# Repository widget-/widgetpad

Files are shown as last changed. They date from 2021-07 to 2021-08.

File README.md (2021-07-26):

# Widgetpad v0

Hi, I'm Widget, and these are the files for my ITG dance/travel pad.

This is the "v0" version, currently in prototype status. I don't plan
on deviating too far from these plans, but there are more adjustments
I still want to make to make the pad easier to manufacture, easier to
fork the source code for, and have it perform more consistently.

You can find me on the Stamina Nation discord causing problems in #pads.

If you live in Chicago and can pass stamina 16's or higher, I would be
interested in having you try out the prototype in person for feedback.
Let me know on Discord.

## Motivation

Current pads either suck or are >$1000. LTEKs are acceptable but need
significant modding using custom microcontrollers and the fragile "penny
mod", so why not just make a new pad?

Currently it's mainly competing with Bandit's
[Build This Travel Pad](https://www.youtube.com/watch?v=y6wGYLE0YI4)
and [Bandit's Terrific Travel Pad](https://github.com/BanditsTerrificTravelPad/bttp)
budget designs.

## Specs

* Aluminum extrusion frame (2020 profile)
* 1/2" acrylic panels
* Arduino Pro Micro microcontroller (but with plans to switch to Teensy
  4.0)
* Force-sensitive resistors for configurable sensitivity
  * Allows for rather extreme sensitivity if made with good tolerances
* Optional LED grid PCBs (WS2812C LEDs)

## License

GNU GPL v2. See LICENSE for full text.

## Demo

YouTube demo video (https://www.youtube.com/watch?v=cCqrD7NEzos)

## Requirements

### Materials

* Arduino Pro Micro or Teensy 2.0 or higher
* 4x 220 ohm resistors
* Some wire to extend FSR connections
* Panels, cut or precut:
  * Either
    * 4x 12mm thickness 280mm x 280mm acrylic panels (1/2" thickness
      11"x11") or larger
  * Or
    * 1x 280mm x 280mm precut acrylic center panel
    * 4x 280mm x 125mm precut acrylic side panels
    * 4x 125mm x 125mm precut acrylic corner panels (optional)
  * Optionally, acetal (a.k.a. POM, Delrin) as a slipperier center panel
    instead of acrylic
* Aluminum extrusion (2020 profile)
  * All taps should be M6 taps with 10mm depth
    * Extra depth is acceptable but may require longer M6 threaded rods
  * 2x 544mm extrusions
    * Drill 6mm at holes at 10mm, 129.5mm, 414.5mm, and 534mm
    * Countersink these holes for your 6mm bolts as well
  * 4x 504mm extrusions, both ends tapped
    * Drill 6mm holes at 109.5mm and 394.5mm
    * For 2 extrusions, countersink these holes for your 6mm bolts as
      well
    * For the other 2 extrusions, extra holes for wiring recommended
  * 2x 265mm extrusions, both ends tapped
    * Extra holes through the center for wiring recommended
  * 4x 99.5mm extrusions, both ends tapped
    * Extra holes through the center for wiring recommended
* Force sensitive resistors (4x 200mm [Interlink 408](https://buyinterlinkelectronics.com/collections/new-standard-force-sensors/products/fsr-model-408-200mm-length) or 8x
  [Interlink 400](https://buyinterlinkelectronics.com/collections/new-standard-force-sensors/products/fsr-model-400))
* 12x countersunk M6x30mm bolts
* 12x hex-head M6x30mm bolts
* 4x M6x40mm threaded rods
* 16x M6 threaded inserts for plastic
* 40x M5x10 bolts
* 40x M5 hammer nuts for 2020 aluminum extrusion
* An "engineering" filament for 3D printed parts, such as PETG, nylon,
  or polycarbonate
* Optional: cross brackets and angle brackets for stability
* Optional: rubber bumpers for floor safety and/or better pad sensitivity
* Optional: 128 [WS2812C-5050](https://lcsc.com/product-detail/Light-Emitting-Diodes-LED_5050-RGBIntegrated-Light-4Pin_C114587.html) LEDs for PCBs
* Optional: 8x 1x2 2.54mm-pitch right-angle male PCB headers for PCBs
* Optional: 4x [5.04mm-pitch 1x2 screw terminals](https://lcsc.com/product-detail/Screw-terminal_Ningbo-Kangnex-Elec-WJ500V-5-08-2P_C8465.html) for PCBs
* Optional: 8x [5.04mm-pitch 1x3 screw terminals](https://lcsc.com/product-detail/Screw-terminal_Ningbo-Kangnex-Elec-WJ500V-5-08-3P_C72334.html) for PCBs

### Equipment

* Table saw if acrylic cutting needed
* Drill press with 6mm (1/4") drill bit and 45° countersink bit
* Table router and roundover bit or lots of sandpaper for smooth edges
* 3mm and 4mm allen keys
* 3D printer for panel mounts
* A heated tool of some sort, such as a soldering iron or a lighter and
  a rod of some type, for inserting the threaded inserts
* Soldering iron is required if assembling PCBs
* DuPont wire crimpers may be useful for making "extension cords" for
  the FSR connectors

### 3D printed parts

3D printed parts can be found in the `3d/` folder.

Parts are designed using [OpenSCAD](https://openscad.org/) with the
[BOSL2](https://github.com/revarbat/BOSL2) library. OpenSCAD nightlies
and BOSL2 master branch are recommended.

Corner bracket mounts will need to be 3D printed to connect the panels
to the aluminum frame.

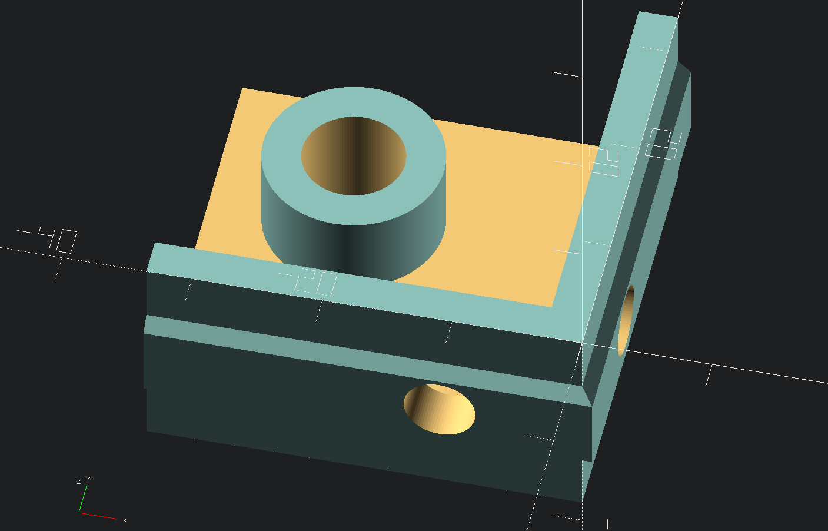
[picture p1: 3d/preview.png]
3D printed corner bracket


Strong filaments, at a minimum PETG but preferably
nylon or polycarbonate will be required. Brittle filaments like PLA,
ABS, HIPS, and ASA may crack. High-rigidity TPU filaments (Shore
hardness 98A or higher) may work, but soft filaments may cause the
panels to slide during play.

A soldering iron or other heating tool will be needed to melt the
threaded inserts into the 3D printed part for the panels to connect to.

PCB mounts may also be 3D printed.

A housing will eventually be designed for the microcontroller but not
as part of v0.

### PCBs

#### Microcontroller breakout

The microcontroller breakout is for a Teensy 4.0 or Teensy 4.1.

The Teensy 4.0 will allow control of up to 10 FSRs, which can map to
up to 10 panels, or 2 FSRs on up to 5 panels.

The Teensy 4.1 will allow control of up to 18 FSRs, which allows an
amount of flexibility with regards to a high-end setup:

* 4 FSRs on each of 4 panels (dance)
* 2 FSRs on each of 8 or 9 panels (techno)
* 2 or 3 FSRs on 4 panels and 4 on a center panel (pump)
* 4 FSRs on 4 panels, and 2 on a center panel (pump)

The breakout also has:

* A 3-pin JST-HX connection for panel LEDs
* 9 LEDs for checking FSR pressed status
* 4 external buttons, for an external arcade button assembly
* 3 internal buttons for controlling LED brightness, and triggering
  an as-yet-unwritten pad calibration
* A buzzer or speaker, to add audio "tactility" to pressing the panels
* A jumper to bridge USB power with the external power input for LEDs

The breakout is designed using KiCAD and uses
[teensy_library](https://github.com/XenGi/teensy_library) and
[teensy.pretty](https://github.com/XenGi/teensy.pretty) by
[XenGi](https://github.com/XenGi), released under the BSD license.

#### Panels

The PCBs are designed using [KiCAD](https://www.kicad.org/).

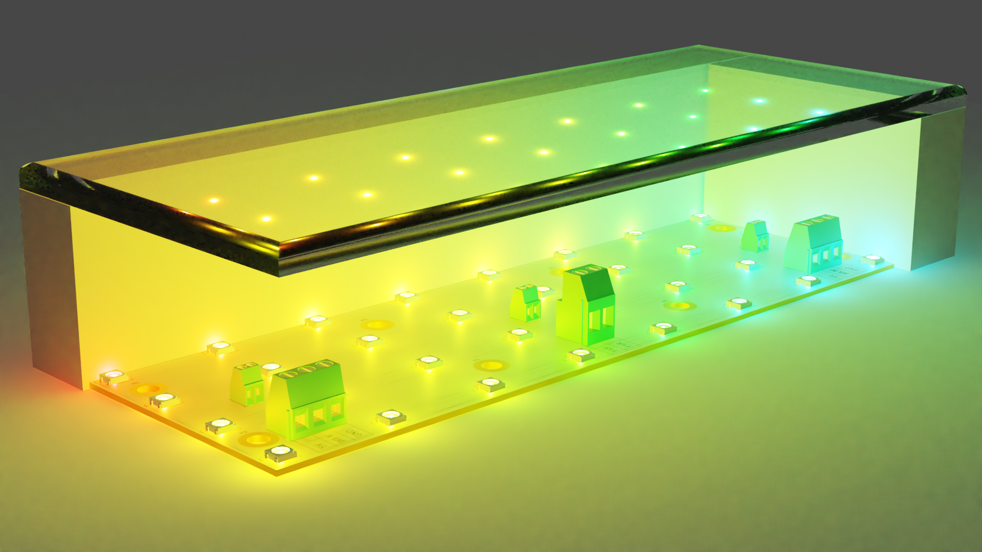
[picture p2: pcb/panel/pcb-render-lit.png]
PCB Render


The PCBs each hold an 8x4 grid of WS2812C LEDs. An external 5V power
source is recommended if using LEDs.

Each PCB has screw terminals for connecting the WS2812C inputs and
outputs. In addition, there are 3 positions of screw terminals and
headers for connecting one or more FSRs. Multiple FSRs would be wired
in parallel.

## Construction

### Frame

1) Cut all aluminum extrusion pieces to length, if not precut
2) Cut drills and countersinks in extrusion
3) Tap all extrusion pieces 10mm deep except the two longest ones, if
   not pretapped
4) Use threaded rods to attach small extrusions "through" the two longer
   center ones
5) Bolt the four second-longest extrusions to the longest two extrusions
6) Insert threaded inserts (using heat) into 3D printed panel mounts
7) Attach 3D printed panel mounts to corners of frame using M5 hammer
   nuts
8) Optionally add cross braces and corner brackets, and add rubber feet
   to the bottom of the frame

### Panels

1) Cut all panels to correct size
2) Preferably using a drill press, cut holes 30mm inset from each corner
   * Four holes on the center panel
   * Two adjacent holes on the edge panels
   * Two opposing holes on the corner panels
3) Use a countersink bit to countersink the holes
4) Using a table router with a roundover bit or lots of sandpaper,
   smooth the edges so that your socks don't get torn up

### Wiring

This pad uses typical wiring for FSR-based pads. Each FSR should connect
to an analog pin an the microcontroller with a 220 ohm pulldown resistor
with the other side connected to VCC.

LED boards will need a connection to VCC, GND, and a data pin, typically
D10 on the Arduino Pro Micro.

An external 5V power source is recommended if using LEDs.

One or more large capacitors (47μF or larger) across +5V and GND may
help with signal stability if the LEDs are causing noise in the FSR
signals.

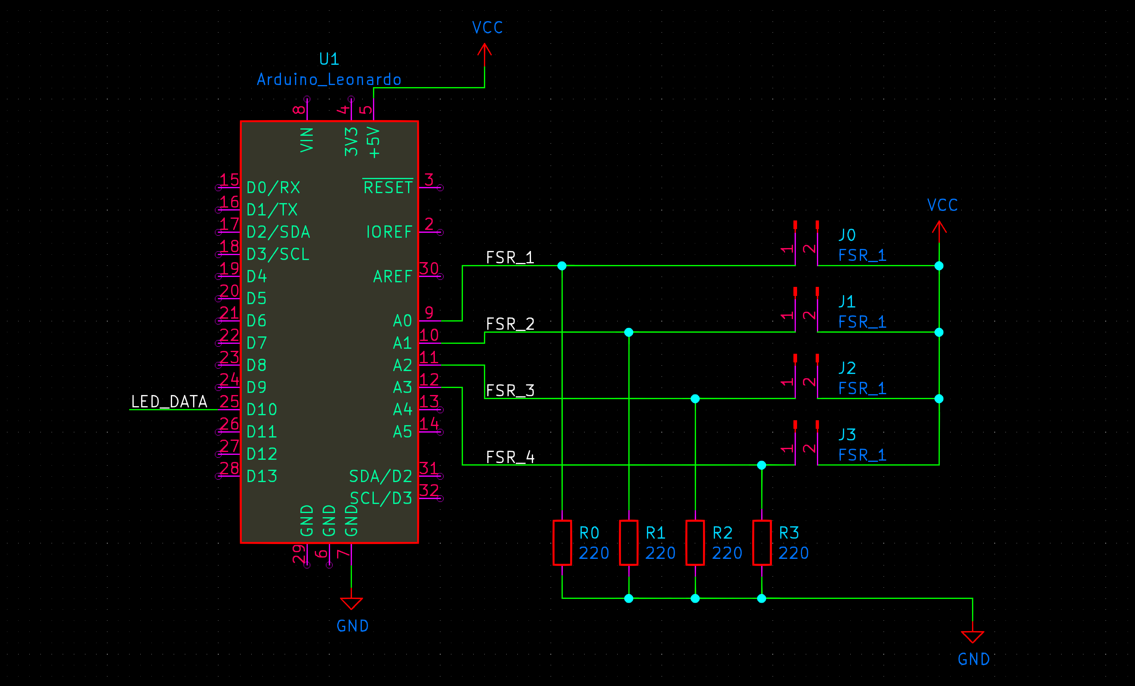
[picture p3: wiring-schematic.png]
Wiring diagram


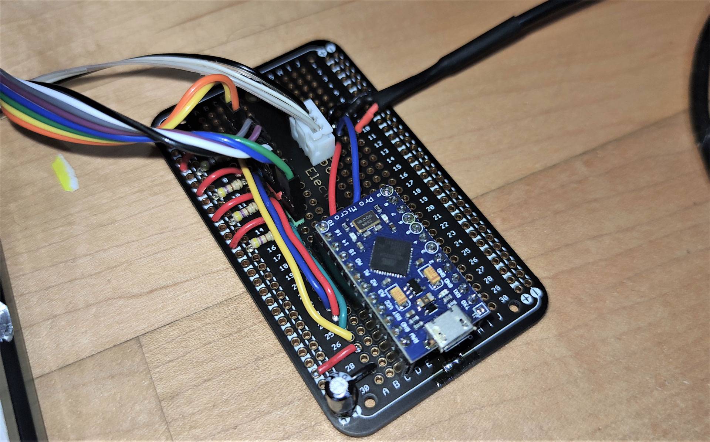
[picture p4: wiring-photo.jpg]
Wiring photo


See also [this diagram](https://cdn.discordapp.com/attachments/591851159795400734/841802090543054849/Untitled-1.png) by Bandit.

## Dimensions

The dimensions are currently calculated using Fusion 360, but I hate
Fusion 360 so eventually I'll change it over to OpenSCAD as well.

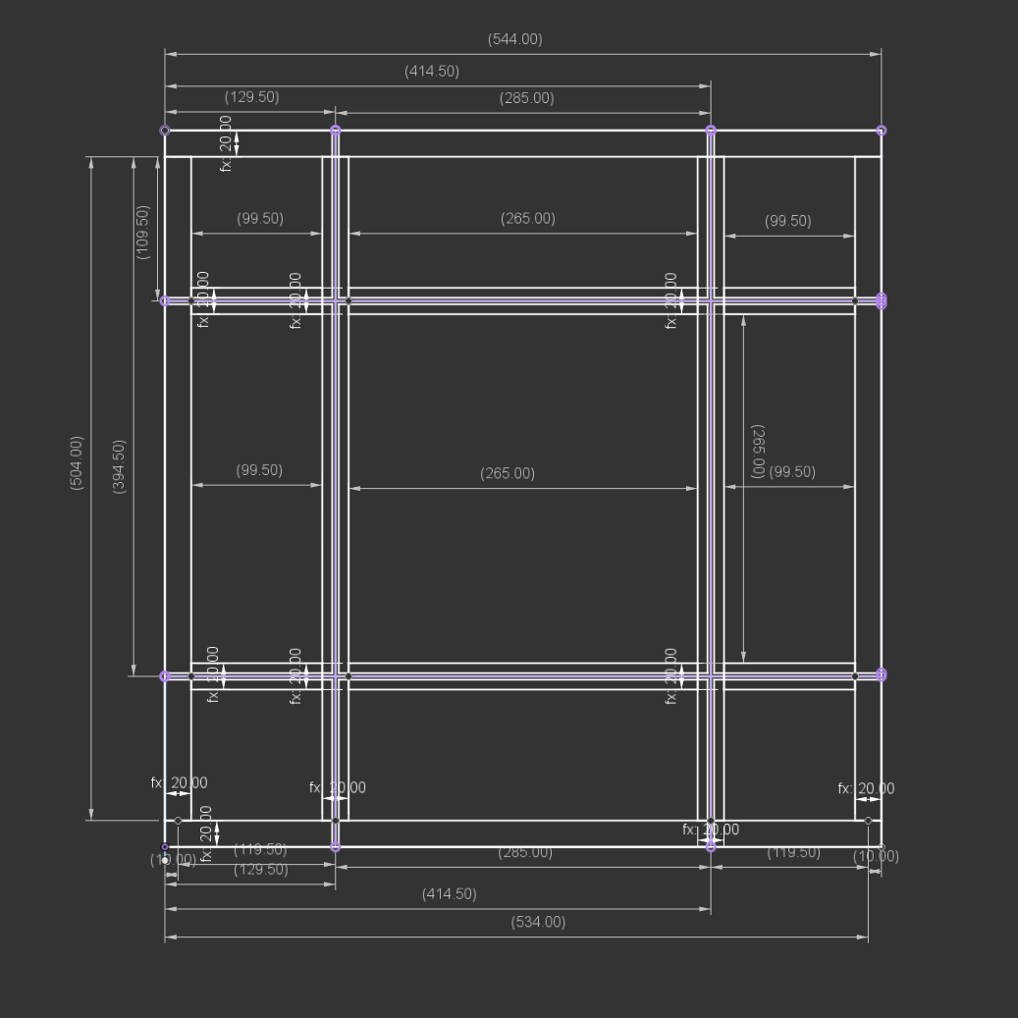
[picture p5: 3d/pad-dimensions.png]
Pad dimensions


## Firmware

The firmware is still a work in progress and can be found at
[widget-/bttp-firmware](https://github.com/widget-/bttp-firmware). It is
a fork of Bandit's [BTTP](https://github.com/BanditsTerrificTravelPad/bttp)
pad's firmware.

Currently it supports joystick or keyboard input, and allows an arbitrary
amount of buttons with corresponding optional LED strips. Sensitivity
can be adjusted either in the firmware or with a tool such as the
[bttp-config-tool](https://github.com/BanditsTerrificTravelPad/bttp-config-tool).

## Special thanks

* Bandit, for motivating me to make this pad, as well as giving me one
  of his prototype pads to play on.
* [dominick](https://www.youtube.com/channel/UCpeNRVOVrqx_lras7hbOOrQ)
  and [teejusb](https://github.com/teejusb) for their help and experience
* The rest of #pads for keeping me motivated
* [South Side Hackerspace](https://sshchicago.org/), for having all the equipment used to create
  the prototype

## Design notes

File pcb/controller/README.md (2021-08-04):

# Teensy 4.0/4.1 Breakout PCB

This is a breakout board for the Teensy 4.0 or Teensy 4.1
microcontroller, intended for use with custom dance pads for games like
ITG and Pump It Up.

This PCB is designed in KiCAD. If the dependencies for the board are not
detected automatically, add the common_lib folder next to this folder
to your KiCAD's search paths for both libraries and footprints.

## Features

* Many FSR outputs with 10kΩ resistors
  * 18 outputs with Teensy 4.1
  * 10 outputs with Teensy 4.0
* Status LEDs for FSR activation status
* 3-pin JST-XH connector for WS2811/WS2812 panel LED boards or strips
* Internal buttons for controlling LED brightness and activating pad
  automatic calibration
* Connection points for external navigation buttons
* Buzzer for audio feedback
* DC barrel jack connector for external LED power
  * Jumper for using USB power to power LEDs instead
* Headers for all soldered Teensy pins, to allow for use cases beyond
  just this board

## License

GNU GPL v2. See the LICENSE file in this project's root for full text.

## Schematic

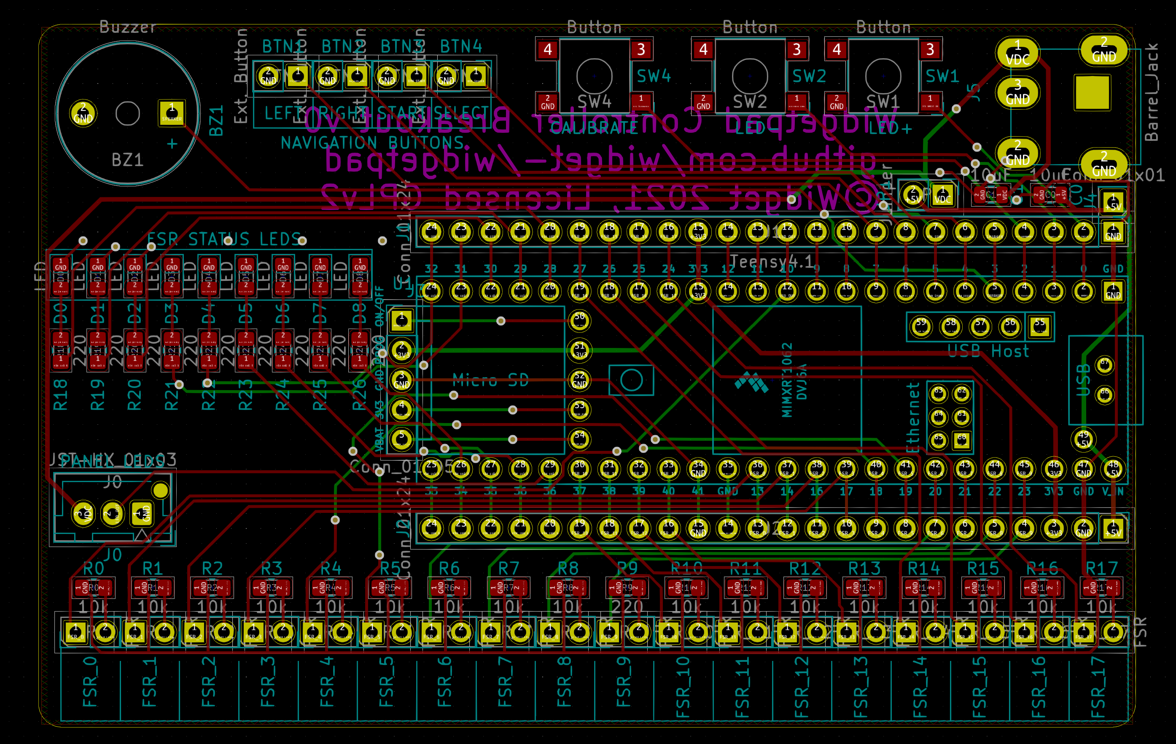
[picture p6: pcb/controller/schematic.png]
Board schematic


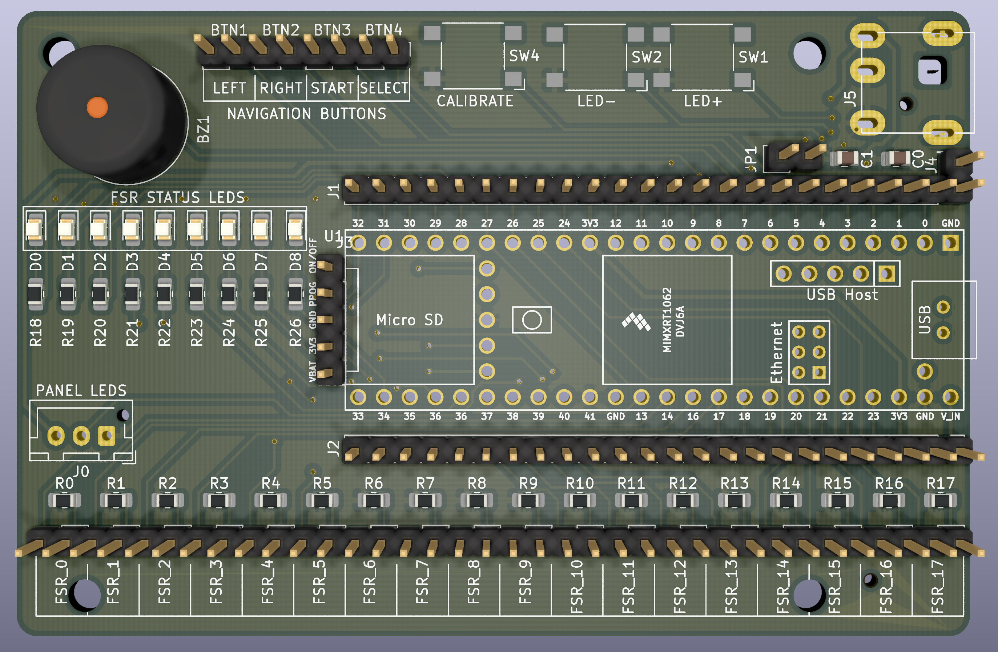
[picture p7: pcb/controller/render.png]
Board render


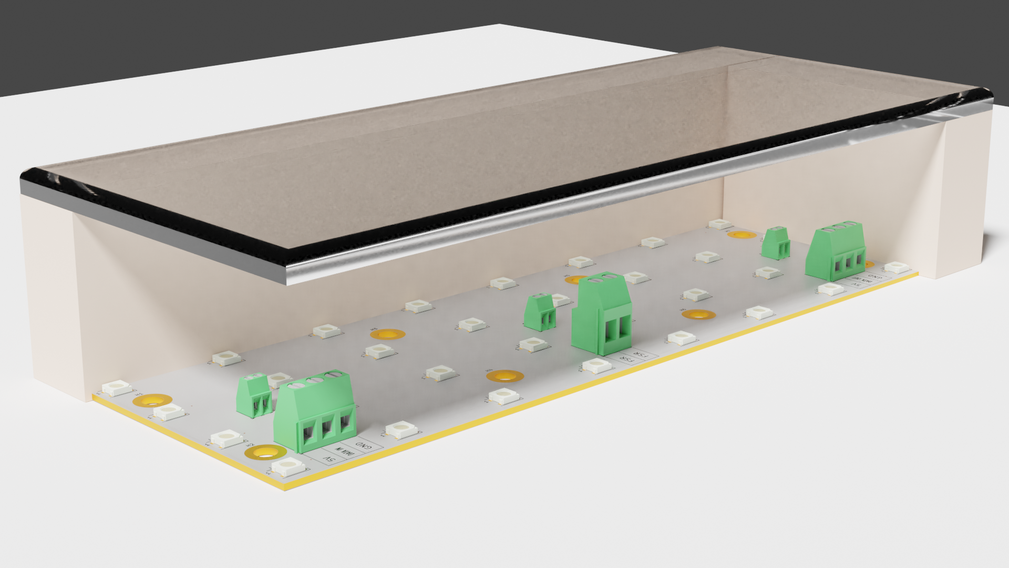
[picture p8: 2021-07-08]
pcb/panel_led/pcb-render-unlit.png

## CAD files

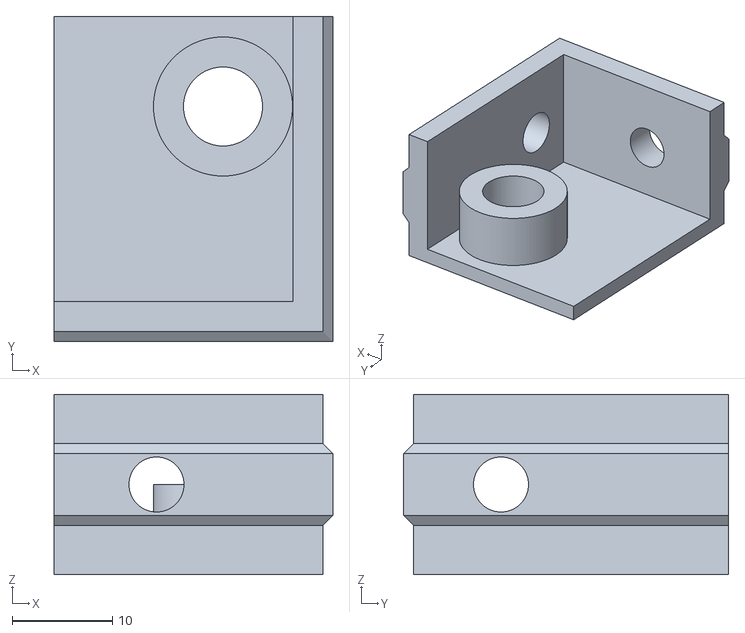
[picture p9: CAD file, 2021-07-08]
3d/dance-pad-edgeL-corner-bracket.stl
27.9 x 32.5 x 18.0

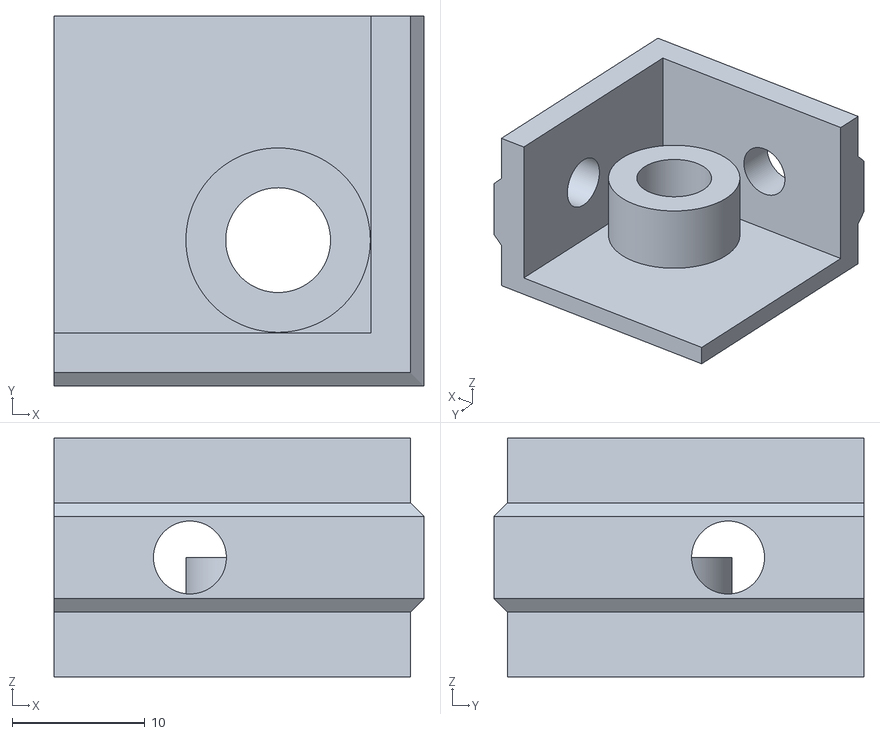
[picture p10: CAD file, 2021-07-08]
3d/dance-pad-corner-corner-bracket.stl
27.9 x 27.9 x 18.0

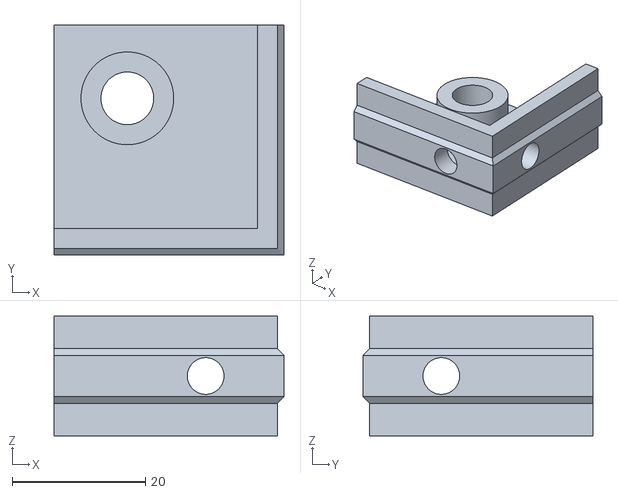
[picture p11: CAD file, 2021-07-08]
3d/dance-pad-center-corner-bracket.stl
34.5 x 34.5 x 18.0

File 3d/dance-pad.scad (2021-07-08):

// This model requires the BOSL2 library. Get it from https://github.com/revarbat/BOSL2
include <BOSL2/std.scad>

corner_inset = 29;

extrusion_width = 20;
extrusion_height = 20;
extrusion_notch = 6.2;
extrusion_protrusion = 1;

2020_bolt_diameter = 5.5;
2020_bolt_length = 14;
2020_cap_diameter = 10;
2020_cap_height = 1.5;
nut_diameter = 8;
nut_thickness = 4.6;

thickness = 3;
base_thickness = 2;
insert_thickness = 8;

panel_width = 280;
panel_thickness = 25.4/4;
panel_bolt_diameter = 6;

insert_diameter = 7.9;
insert_depth = 8;

panel_spacing = 5;

extrusion_height_tolerance = 2;

function option(index, a, b, c) =
    (index == 1) ? a :
    (index == 2) ? b :
    c;


$fa = 0.5;
$fs = 0.2;

module panel_preview() {
    // center panel
    // left(panel_width/2-extrusion_width/4-panel_spacing/2)
    left(panel_width/2-extrusion_width)
    back(panel_width/2-extrusion_width)
    difference() {
        cuboid([panel_width, panel_width, panel_thickness], rounding=panel_thickness/2, edges=TOP);

        xcopies(panel_width-corner_inset*2)
        ycopies(panel_width-corner_inset*2)
        cyl(d=panel_bolt_diameter, h=panel_thickness+1);
    }
}

module corner_bracket(inset_x, inset_y, extra_bolt_offset_x=0, extra_bolt_offset_y=0) {
    _width = inset_x + panel_bolt_diameter + thickness + extra_bolt_offset_x;
    _length = inset_y + panel_bolt_diameter + thickness + extra_bolt_offset_y;
    difference() {
        // base cube
        union() {
            cuboid([_width, _length, extrusion_height-extrusion_height_tolerance], anchor=RIGHT+FRONT+TOP);
            down((extrusion_height-extrusion_height_tolerance)/2) {
                cuboid([_width, extrusion_protrusion*2, extrusion_notch+extrusion_protrusion*2], chamfer=extrusion_protrusion, edges="X", anchor=RIGHT);
                cuboid([extrusion_protrusion*2, _length, extrusion_notch+extrusion_protrusion*2], chamfer=extrusion_protrusion, edges="Y", anchor=FRONT);
                cuboid([extrusion_protrusion*2, extrusion_protrusion*2, extrusion_notch+extrusion_protrusion*2], chamfer=extrusion_protrusion, edges=["X", "Y"]);
            }
        }

        // cut out inner section
        translate([-thickness, thickness, base_thickness])
        cuboid([_width, _length, extrusion_height-extrusion_height_tolerance], anchor=RIGHT+FRONT+TOP);

        // hole for threaded insert
        left(inset_x)
        back(inset_y)
        cyl(h=extrusion_height*2+1, d=insert_diameter);

        // 2020 mounting screws
        // translate([-(thickness+2020_cap_diameter/2+2020_cap_height/2), thickness+2020_cap_diameter/2+2020_cap_height, -(extrusion_height-extrusion_height_tolerance)/2])
        // translate([-thickness, thickness, -(extrusion_height-extrusion_height_tolerance)/2])
        down((extrusion_height-extrusion_height_tolerance)/2)
        left(thickness)
        back(thickness+2020_cap_diameter/2+2020_cap_height/2 + extra_bolt_offset_y) {
            cyl(h=max(_width, _length)*2+1, d=2020_bolt_diameter, orient=LEFT);
            cyl(h=2020_bolt_length, d=2020_cap_diameter, orient=LEFT, anchor=BOTTOM);
        }

        down((extrusion_height-extrusion_height_tolerance)/2)
        back(thickness) 
        left(thickness+2020_cap_diameter/2+2020_cap_height/2 + extra_bolt_offset_x) {
            cyl(h=max(_width, _length)*2+1, d=2020_bolt_diameter, orient=BACK);
            cyl(h=2020_bolt_length, d=2020_cap_diameter, orient=BACK, anchor=BOTTOM);
        }
    }
    
    left(inset_x)
    back(inset_y)
    down((extrusion_height-extrusion_height_tolerance)/2)
    tube(h=insert_thickness, id=insert_diameter, od=insert_diameter+thickness*2, anchor=TOP);
}

module corner_bracket_center_panel() {
    inset = corner_inset - extrusion_width/4 - panel_spacing/2;
    corner_bracket(inset, inset, 2, 2);
}

module corner_bracket_edge_panel_l() {
    inset_x = corner_inset - extrusion_width;
    inset_y = corner_inset - extrusion_width/4 - panel_spacing/2;
    corner_bracket(inset_x, inset_y, insert_diameter);
}

module corner_bracket_edge_panel_r() {
    inset_x = corner_inset - extrusion_width/4 - panel_spacing/2;
    inset_y = corner_inset - extrusion_width;
    corner_bracket(inset_x, inset_y, 0, insert_diameter);
}
module corner_bracket_corner_panel() {
    inset_x = corner_inset - extrusion_width;
    inset_y = corner_inset - extrusion_width;
    corner_bracket(inset_x, inset_y, insert_diameter, insert_diameter);
}

// corner_bracket_center_panel();

// corner_bracket_edge_panel_l();
corner_bracket_edge_panel_r();

// corner_bracket_corner_panel();

if ($preview)
color("#FFFFFF66")
up(panel_thickness/2)
panel_preview();

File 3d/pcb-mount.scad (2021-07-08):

// This model requires the BOSL2 library. Get it from https://github.com/revarbat/BOSL2
include <BOSL2/std.scad>


hole_spacing = 44;
hole_length = 35;
hole_diameter = 5.5;

extrusion_notch = 6; // 6.2 officially
extrusion_protrusion = 1; // 1mm chamfer makes 8mm beginning of opening
extrusion_height = 20;
extrusion_height_tolerance = 2;

2020_bolt_diameter = 5.5;
2020_bolt_length = 14;

thickness = 4;
base_thickness = 2;
screw_extra_spacing = 5;

_width = hole_spacing + screw_extra_spacing * 2 + hole_diameter;
_length = hole_length + screw_extra_spacing*2 + thickness;

$fa = 1;
$fs = .5;

difference() {
    union() {
        cuboid([_width, thickness, extrusion_height-extrusion_height_tolerance], anchor=FRONT+BOTTOM);
        up((extrusion_height-extrusion_height_tolerance)/2)
        cuboid([_width, extrusion_protrusion*2, extrusion_notch+extrusion_protrusion*2], chamfer=extrusion_protrusion, edges="X");
    }

    up((extrusion_height-extrusion_height_tolerance)/2)
    back(thickness)
    xcopies(l=hole_spacing)
    cyl(h=max(_width, _length)*2+1, d=2020_bolt_diameter, orient=BACK);
}

xcopies(l=hole_spacing)
difference() {
    cuboid([hole_diameter+screw_extra_spacing*2, _length, base_thickness], anchor=FRONT+BOTTOM, rounding=screw_extra_spacing, edges=[BACK+LEFT, BACK+RIGHT]);
    back(thickness+hole_length/2+screw_extra_spacing)
    cuboid([hole_diameter, hole_length, base_thickness*3], rounding=hole_diameter/2, edges="Z");
}

xflip_copy(_width/2-(hole_diameter+screw_extra_spacing*2-base_thickness)/2)
yrot(-90)
back(thickness)
zcopies(hole_diameter+screw_extra_spacing*2-base_thickness)
right_triangle([(extrusion_height-extrusion_height_tolerance)/2, (extrusion_height-extrusion_height_tolerance)/2, base_thickness]);

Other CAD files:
3d/dance-pad-edgeR-corner-bracket.stl

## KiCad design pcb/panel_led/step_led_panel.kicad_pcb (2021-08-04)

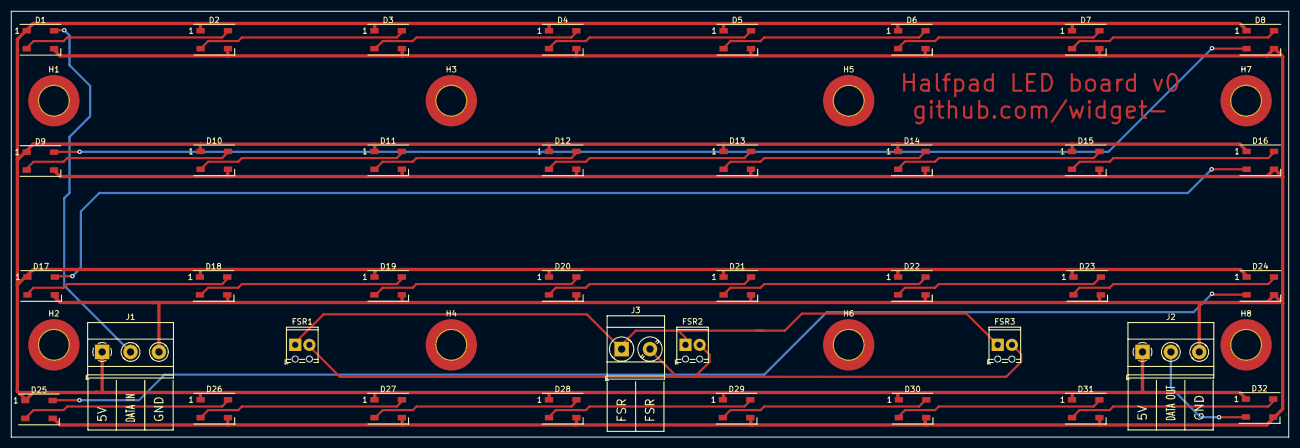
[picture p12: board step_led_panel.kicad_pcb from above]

Board: 2 copper layers, 228.6 x 76.2 mm, 46 parts (0 on the bottom side), 37 nets.

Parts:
D1, D2, D3, D4, D5, D6, D7, D8, D9, D10, D11, D12, D13, D14, D15, D16, D17, D18, D19, D20, D21, D22, D23, D24, D25, D26, D27, D28, D29, D30, D31, D32: WS2812; LED_WS2812B_PLCC4_5.0x5.0mm_P3.2mm
FSR1, FSR2, FSR3: Screw_Terminal_01x02; TerminalBlock_Phoenix_MPT-0,5-2-2.54_1x02_P2.54mm_Horizontal
H1, H2, H3, H4, H5, H6, H7, H8: MountingHole; MountingHole_5.3mm_M5_DIN965_Pad_TopOnly
J1, J2: Screw_Terminal_01x03; TerminalBlock_Phoenix_MKDS-1,5-3-5.08_1x03_P5.08mm_Horizont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
J3: Screw_Terminal_01x02; TerminalBlock_Phoenix_MKDS-3-2-5.08_1x02_P5.08mm_Horizontal

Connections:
+5V: D1.1, D2.1, D3.1, D4.1, D5.1, D6.1, D7.1, D8.1, D10.1, D11.1, D12.1, D13.1, D14.1, D15.1, D16.1, D18.1, D19.1, D20.1, D21.1, D22.1, D23.1, D24.1, D26.1, D27.1, D28.1, D29.1, D30.1, D31.1, D32.1, J1.1, J2.1
/D_IN: D1.4, J1.2
/D_OUT: D32.2, J2.2
GND: D1.3, D2.3, D3.3, D4.3, D5.3, D6.3, D7.3, D8.3, D10.3, D11.3, D12.3, D13.3, D14.3, D15.3, D16.3, D18.3, D19.3, D20.3, D21.3, D22.3, D23.3, D24.3, D26.3, D27.3, D28.3, D29.3, D30.3, D31.3, D32.3, J1.3, J2.3
unnamed: D1.2, D2.4
unnamed: D2.2, D3.4
unnamed: D3.2, D4.4
unnamed: D4.2, D5.4
unnamed: D5.2, D6.4
unnamed: D6.2, D7.4
unnamed: D7.2, D8.4
unnamed: D8.2, D9.4
unnamed: D10.2, D11.4
unnamed: D9.2, D10.4
unnamed: D11.2, D12.4
unnamed: D12.2, D13.4
unnamed: D13.2, D14.4
unnamed: D14.2, D15.4
unnamed: D15.2, D16.4
unnamed: D16.2, D17.4
unnamed: D17.2, D18.4
unnamed: D18.2, D19.4
unnamed: D19.2, D20.4
unnamed: D20.2, D21.4
unnamed: D21.2, D22.4
unnamed: D22.2, D23.4
unnamed: D23.2, D24.4
unnamed: D24.2, D25.4
unnamed: D25.2, D26.4
unnamed: D26.2, D27.4
unnamed: D27.2, D28.4
unnamed: D28.2, D29.4
unnamed: D29.2, D30.4
unnamed: D30.2, D31.4
unnamed: D31.2, D32.4
unnamed: FSR1.1, FSR2.1, FSR3.1, J3.1
unnamed: FSR1.2, FSR2.2, FSR3.2, J3.2

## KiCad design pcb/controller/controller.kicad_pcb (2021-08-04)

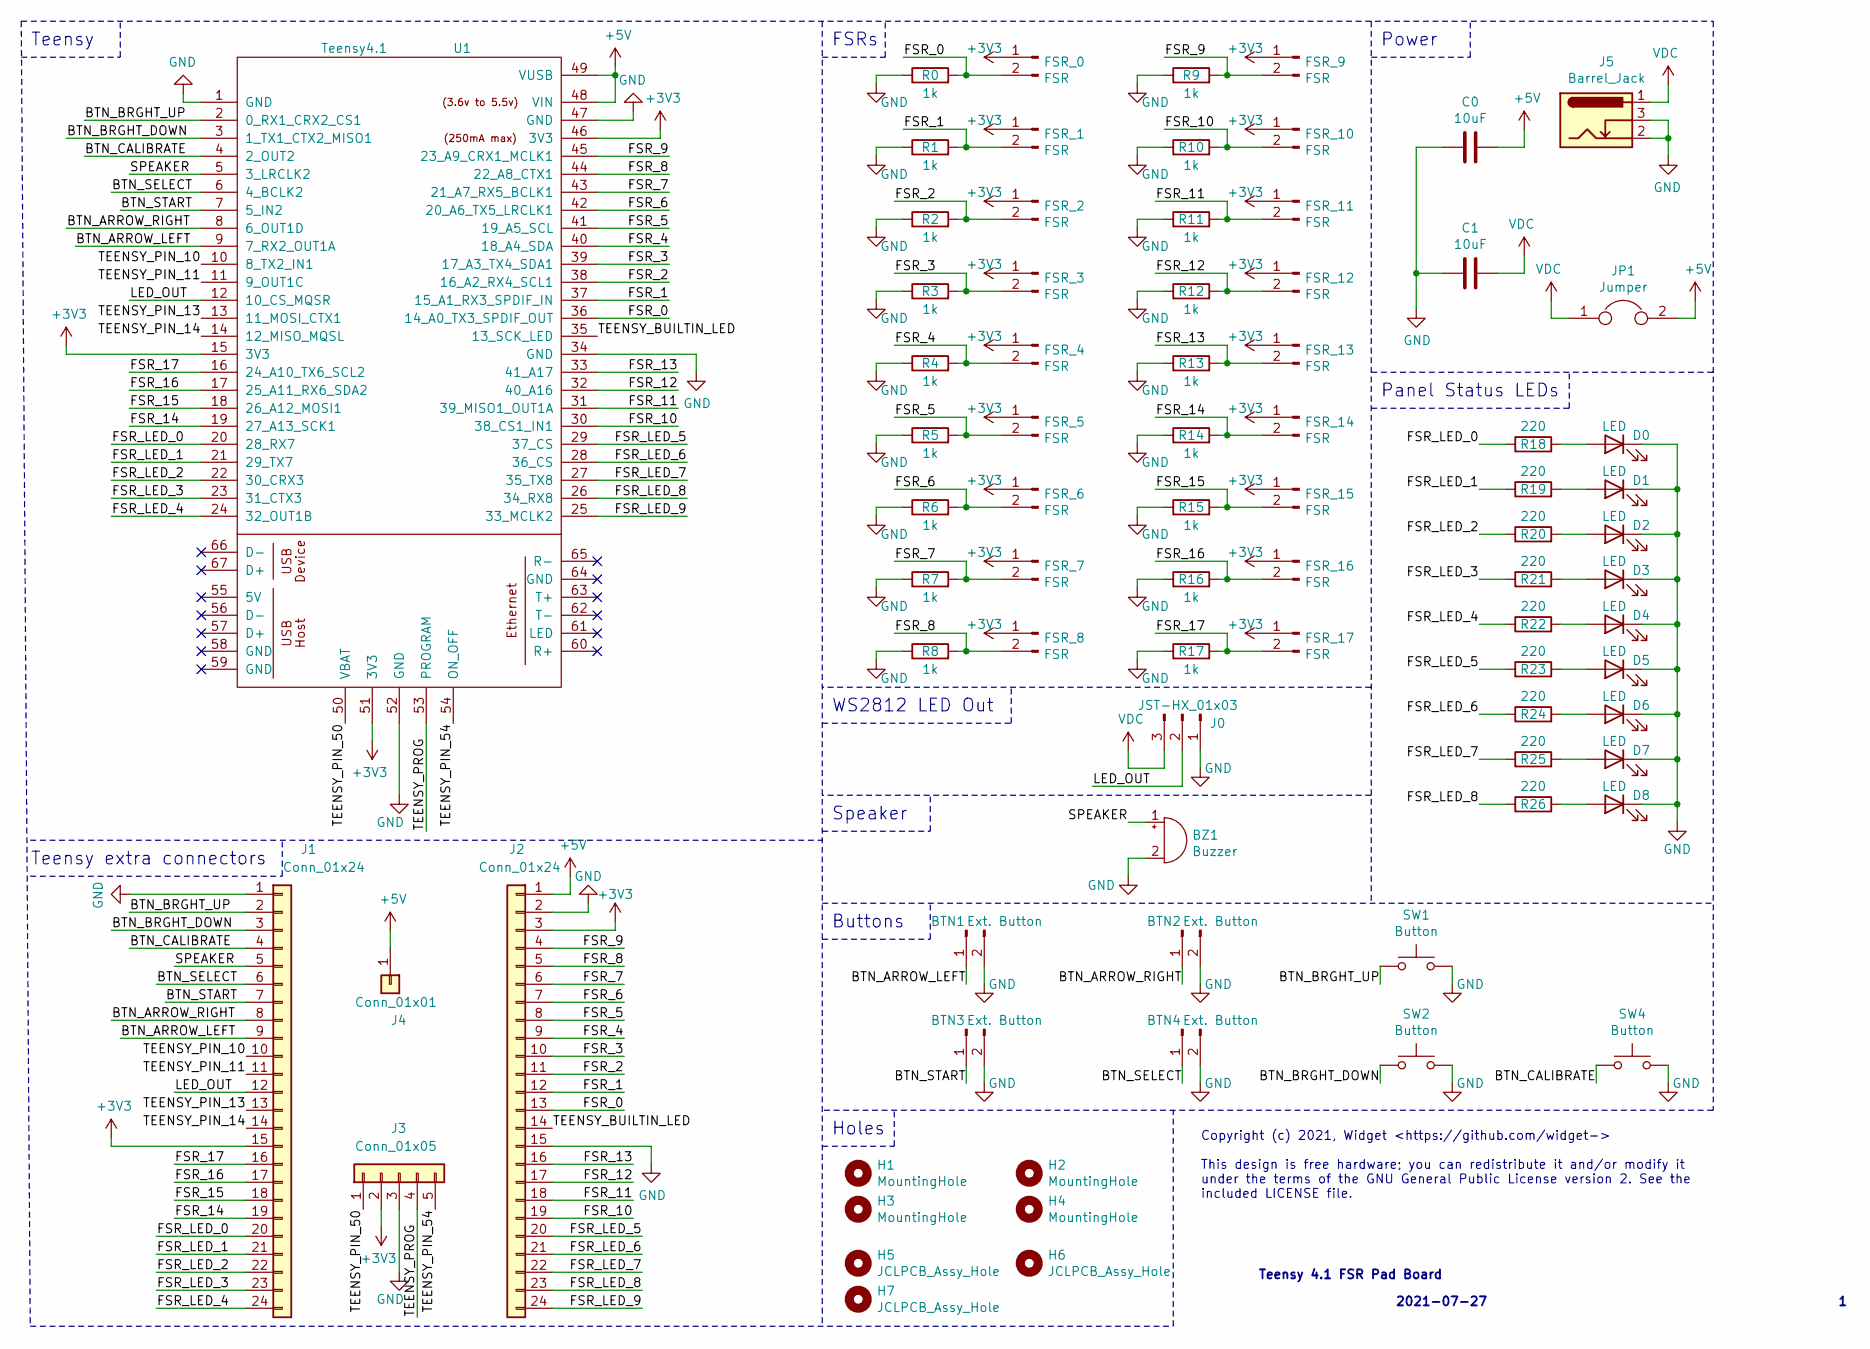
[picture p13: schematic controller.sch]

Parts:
BTN1, BTN2, BTN3, BTN4: Ext. Button; PinHeader_1x02_P2.54mm_Vertical
BZ1: Buzzer; Buzzer_12x9.5RM7.6
C0, C1: 10uF; C_0805_2012Metric
D0, D1, D2, D3, D4, D5, D6, D7, D8: LED; LED_0805_2012Metric_Pad1.15x1.40mm_HandSolder
FSR_0, FSR_1, FSR_2, FSR_3, FSR_4, FSR_5, FSR_6, FSR_7, FSR_8, FSR_9, FSR_10, FSR_11, FSR_12, FSR_13, FSR_14, FSR_15, FSR_16, FSR_17: FSR; PinHeader_1x02_P2.54mm_Vertical
H1, H2, H3, H4: MountingHole; MountingHole_3.2mm_M3
H5, H6, H7: JCLPCB_Assy_Hole; JCLPCB_Assembly_Hole
J0: JST-HX_01x03; JST_XH_B3B-XH-AM_1x03_P2.50mm_Vertical
J1, J2: Conn_01x24; PinHeader_1x24_P2.54mm_Vertical
J3: Conn_01x05; PinHeader_1x05_P2.54mm_Vertical
J4: Conn_01x01; PinHeader_1x01_P2.54mm_Vertical
J5: Barrel_Jack; XKB_Connectivity_DC-044A-2.5A
JP1: Jumper; PinHeader_1x02_P2.54mm_Vertical
R0, R1, R2, R3, R4, R5, R6, R7, R8, R9, R10, R11, R12, R13, R14, R15, R16, R17: 1k; R_0805_2012Metric_Pad1.20x1.40mm_HandSolder
R18, R19, R20, R21, R22, R23, R24, R25, R26: 220; R_0805_2012Metric_Pad1.20x1.40mm_HandSolder
SW1, SW2, SW4: Button; SW_SPST_Omron_B3FS-100xP
U1: Teensy4.1; Teensy41

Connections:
+3V3: FSR_0.1, FSR_1.1, FSR_2.1, FSR_3.1, FSR_4.1, FSR_5.1, FSR_6.1, FSR_7.1, FSR_8.1, FSR_9.1, FSR_10.1, FSR_11.1, FSR_12.1, FSR_13.1, FSR_14.1, FSR_15.1, FSR_16.1, FSR_17.1, J1.15, J2.3, J3.2, U1.15 (3V3), U1.46 (3V3), U1.51 (3V3)
+5V: C0.1, J2.1, J4.1, JP1.2, U1.48 (VIN), U1.49 (VUSB)
/BTN_ARROW_LEFT: BTN1.1, J1.9, U1.9 (7_RX2_OUT1A)
/BTN_ARROW_RIGHT: BTN2.1, J1.8, U1.8 (6_OUT1D)
/BTN_BRGHT_DOWN: J1.3, SW2.1, U1.3 (1_TX1_CTX2_MISO1)
/BTN_BRGHT_UP: J1.2, SW1.1, U1.2 (0_RX1_CRX2_CS1)
/BTN_CALIBRATE: J1.4, SW4.1, U1.4 (2_OUT2)
/BTN_SELECT: BTN4.1, J1.6, U1.6 (4_BCLK2)
/BTN_START: BTN3.1, J1.7, U1.7 (5_IN2)
/FSR_0: FSR_0.2, J2.13, R0.2, U1.36 (14_A0_TX3_SPDIF_OUT)
/FSR_1: FSR_1.2, J2.12, R1.2, U1.37 (15_A1_RX3_SPDIF_IN)
/FSR_2: FSR_2.2, J2.11, R2.2, U1.38 (16_A2_RX4_SCL1)
/FSR_3: FSR_3.2, J2.10, R3.2, U1.39 (17_A3_TX4_SDA1)
/FSR_4: FSR_4.2, J2.9, R4.2, U1.40 (18_A4_SDA)
/FSR_5: FSR_5.2, J2.8, R5.2, U1.41 (19_A5_SCL)
/FSR_6: FSR_6.2, J2.7, R6.2, U1.42 (20_A6_TX5_LRCLK1)
/FSR_7: FSR_7.2, J2.6, R7.2, U1.43 (21_A7_RX5_BCLK1)
/FSR_8: FSR_8.2, J2.5, R8.2, U1.44 (22_A8_CTX1)
/FSR_9: FSR_9.2, J2.4, R9.2, U1.45 (23_A9_CRX1_MCLK1)
/FSR_10: FSR_10.2, J2.19, R10.2, U1.30 (38_CS1_IN1)
/FSR_11: FSR_11.2, J2.18, R11.2, U1.31 (39_MISO1_OUT1A)
/FSR_12: FSR_12.2, J2.17, R12.2, U1.32 (40_A16)
/FSR_13: FSR_13.2, J2.16, R13.2, U1.33 (41_A17)
/FSR_14: FSR_14.2, J1.19, R14.2, U1.19 (27_A13_SCK1)
/FSR_15: FSR_15.2, J1.18, R15.2, U1.18 (26_A12_MOSI1)
/FSR_16: FSR_16.2, J1.17, R16.2, U1.17 (25_A11_RX6_SDA2)
/FSR_17: FSR_17.2, J1.16, R17.2, U1.16 (24_A10_TX6_SCL2)
/FSR_LED_0: J1.20, R18.1, U1.20 (28_RX7)
/FSR_LED_1: J1.21, R19.1, U1.21 (29_TX7)
/FSR_LED_2: J1.22, R20.1, U1.22 (30_CRX3)
/FSR_LED_3: J1.23, R21.1, U1.23 (31_CTX3)
/FSR_LED_4: J1.24, R22.1, U1.24 (32_OUT1B)
/FSR_LED_5: J2.20, R23.1, U1.29 (37_CS)
/FSR_LED_6: J2.21, R24.1, U1.28 (36_CS)
/FSR_LED_7: J2.22, R25.1, U1.27 (35_TX8)
/FSR_LED_8: J2.23, R26.1, U1.26 (34_RX8)
/FSR_LED_9: J2.24, U1.25 (33_MCLK2)
/LED_OUT: J0.2, J1.12, U1.12 (10_CS_MQSR)
/SPEAKER: BZ1.1 (-), J1.5, U1.5 (3_LRCLK2)
/TEENSY_BUILTIN_LED: J2.14, U1.35 (13_SCK_LED)
/TEENSY_PIN_10: J1.10, U1.10 (8_TX2_IN1)
/TEENSY_PIN_11: J1.11, U1.11 (9_OUT1C)
/TEENSY_PIN_13: J1.13, U1.13 (11_MOSI_CTX1)
/TEENSY_PIN_14: J1.14, U1.14 (12_MISO_MQSL)
/TEENSY_PIN_50: J3.1, U1.50 (VBAT)
/TEENSY_PIN_54: J3.5, U1.54 (ON_OFF)
/TEENSY_PROG: J3.4, U1.53 (PROGRAM)
GND: BTN1.2, BTN2.2, BTN3.2, BTN4.2, BZ1.2 (+), C0.2, C1.2, D0.1 (K), D1.1 (K), D2.1 (K), D3.1 (K), D4.1 (K), D5.1 (K), D6.1 (K), D7.1 (K), D8.1 (K), J0.1, J1.1, J2.2, J2.15, J3.3, J5.2, J5.3, R0.1, R1.1, R2.1, R3.1, R4.1, R5.1, R6.1, R7.1, R8.1, R9.1, R10.1, R11.1, R12.1, R13.1, R14.1, R15.1, R16.1, R17.1, SW1.2, SW2.2, SW4.2, U1.1 (GND), U1.34 (GND), U1.47 (GND), U1.52 (GND)
unnamed: D0.2 (A), R18.2
unnamed: D1.2 (A), R19.2
unnamed: D2.2 (A), R20.2
unnamed: D3.2 (A), R21.2
unnamed: D4.2 (A), R22.2
unnamed: D5.2 (A), R23.2
unnamed: D6.2 (A), R24.2
unnamed: D7.2 (A), R25.2
unnamed: D8.2 (A), R26.2
VDC: C1.1, J0.3, J5.1, JP1.1

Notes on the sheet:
FSRs
Teensy
WS2812 LED Out
Power
Teensy extra connectors
Speaker
Teensy 4.1 FSR Pad Board
2021-07-27
Copyright (c) 2021, Widget <https://github.com/widget-> This design is free hardware; you can redistribute it and/or modify it under the terms of the GNU General Public License version 2. See the included LICENSE file.
Buttons
Panel Status LEDs
Holes

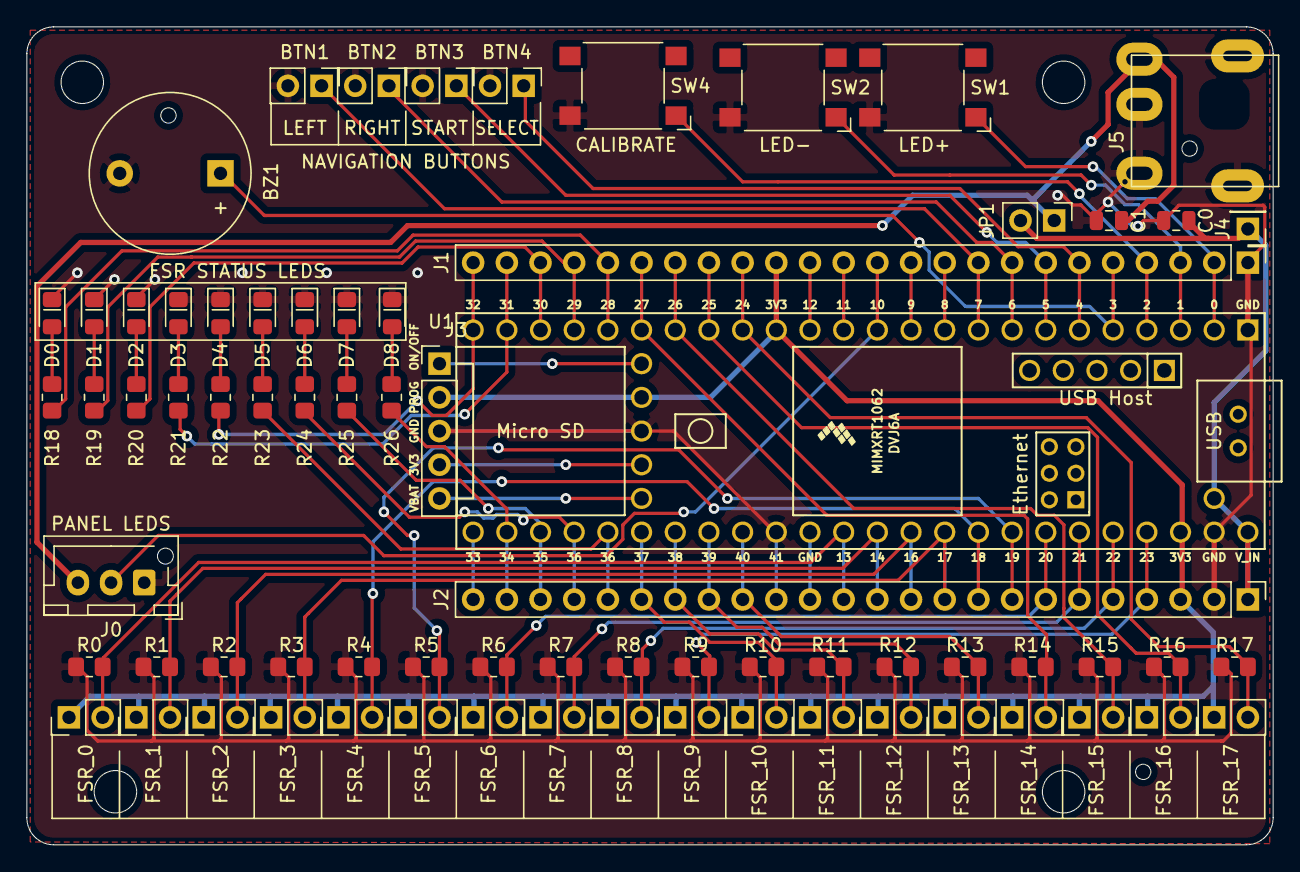
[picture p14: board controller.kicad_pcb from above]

Board: 2 copper layers, 94.0 x 61.7 mm, 79 parts (0 on the bottom side), 58 nets.

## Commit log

2021-07-08 Initial revision for v0 of pad
    [dance-pad-center-corner-bracket.stl, dance-pad-corner-corner-bracket.stl, dance-pad-edgeL-corner-bracket.stl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]
2021-07-20 Move panel PCB to its own subfolder
    [step_led_panel-B_Cu.gbr, step_led_panel-B_Mask.gbr, step_led_panel-B_Paste.gbr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]
2021-07-26 Add controller PCB schematic and unrouted layout
    [controller.kicad_pcb, controller.sch]
2021-07-26 Controller Breakout board v0
2021-08-04 Finalize v0.1 of breakout board to start v0.2
    [controller.kicad_pcb, controller.sch, step_led_panel.kicad_pcb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]

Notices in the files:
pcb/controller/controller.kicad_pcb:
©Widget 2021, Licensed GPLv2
